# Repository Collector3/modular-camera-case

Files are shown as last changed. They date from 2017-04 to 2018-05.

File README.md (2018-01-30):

# Modular Raspberry Pi Camera Cases

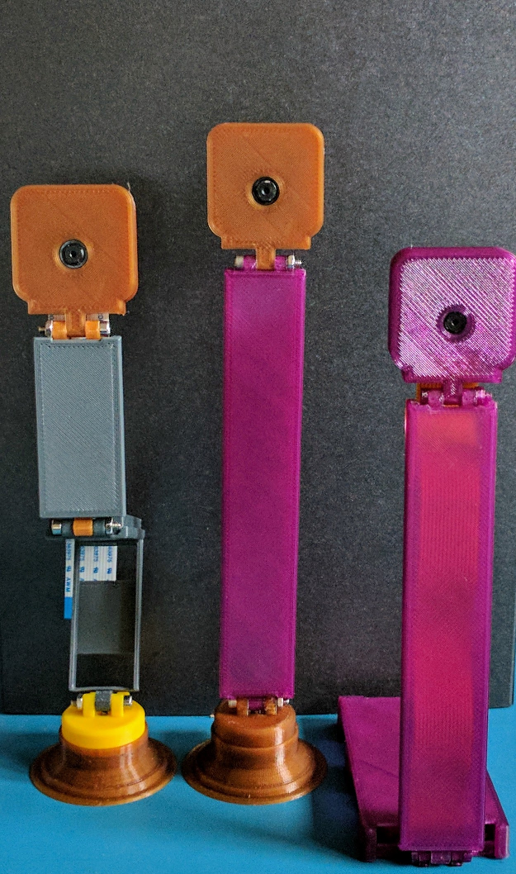
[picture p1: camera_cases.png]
Camera Case


Cases for the Raspberry Pi foundation's camera. v1/v2 are supported.

**Note**: This case needs M2.5 screws and nuts! The bill of materials with a source for getting these is listed below.

## Extrusion Width == 0.48mm

This case is also designed around an extrusion width of 0.48mm for strength (using a 0.4mm E3D nozzle) around small areas and parts. It makes a huge difference, so if the case isn't quite right, try adjusting the extrusion width.

## Assembly / Printing

Choose one of the cases below (they're plated together according to filename). They're also available separately for expansion (if a larger arm is desired, more/less sections, etc).

## Bill of Materials

This BOM lists the amount of screws for each setup. In reality, everything is usually sold in 25+ quantity packs, so just buy M2.5 screws and M2.5 hex nuts. There is extra spacing to use nylock nuts too if desired.

Of course, if you're set on doing so, threading a bit of filament through the
holes and gluing everything together can work just as well (if no future adjustments are desired). Zip ties also work, but don't look as good.

### Various configurations

#### Pi Zero Case + Long Arm

To split these for arranging on a bed in Slic3r, use the 'Split' option at the top [next to scale/cut]. These files include the **v2 camera enclosure by default**. The bottom-most stand is separate as well.

* File: [plated_pi_zero_case.stl](plated_pi_zero_case.stl) [purple, far right in the photos]
* 2x M2.5 x 16mm screw
* 2x M2.5 hex nut

#### Long Arm

* File: [plated_long_arm.stl](plated_long_arm.stl) [purple with brown/bronze top, center]
* 2x M2.5 x 16mm screw
* 2x M2.5 hex nut

#### Multi-jointed Arm

* File: [plated_multi_arm.stl](plated_multi_arm.stl) [yellow base, gray and brown/bronze top, left]
* 4x M2.5 x 16mm screw
* 4x M2.5 hex nut

#### Stand

* File: [Stand.stl](Stand.stl) [Brown/Bronze bottom in pictures]
* 1x: M2.5 x 16mm screw (pushed in through the top or bottom before joining
  with the smaller base [yellow in the picture])

#### RPi OEM Backpack

* File: rpi-zero-oem-case-backpack.stl [Red]
* 1x M2.5 20mm screw + 1x M2.5 Nylock

### Hardware source

(I don't have a good source for a metric hex key, but an appropriately sized one should be in many repair kits and multi-tools)

#### Trimcraft Aviation RC

* M2.5 Plain Hex Nut (25 pcs): https://www.trimcraftaviationrc.com/index.php?route=product/product&product_id=137
* M2.5 x 16mm Socket Cap Screw (25 pcs): https://www.trimcraftaviationrc.com/index.php?route=product/product&product_id=199

##### Materials Used (1.75mm PLA)

(These are the various types of PLA used in the photo above; basically a mix-and-match of whatever was loaded into the machine on the day that these were made)

* Purple: Ultimachine Purple Translucent PLA

* Yellow: Prusa PLA, OEM: [Plasty Mladec](http://www.plastymladec.cz/) 

* Brown: Proto-pasta High Performance HTPLA - Aromatic Coffee

* Gray: Atomic Filament Extreme Impact Gun Metal Gray v2 (a flex test of the impact modifier is present on the far left casing)

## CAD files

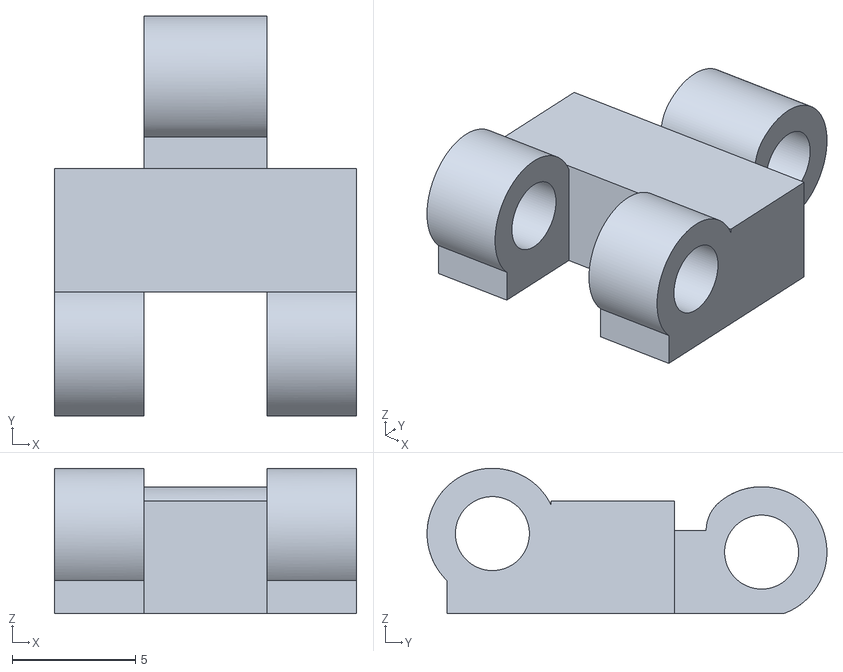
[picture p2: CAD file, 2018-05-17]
Spacer.stl
12.2 x 16.2 x 5.90

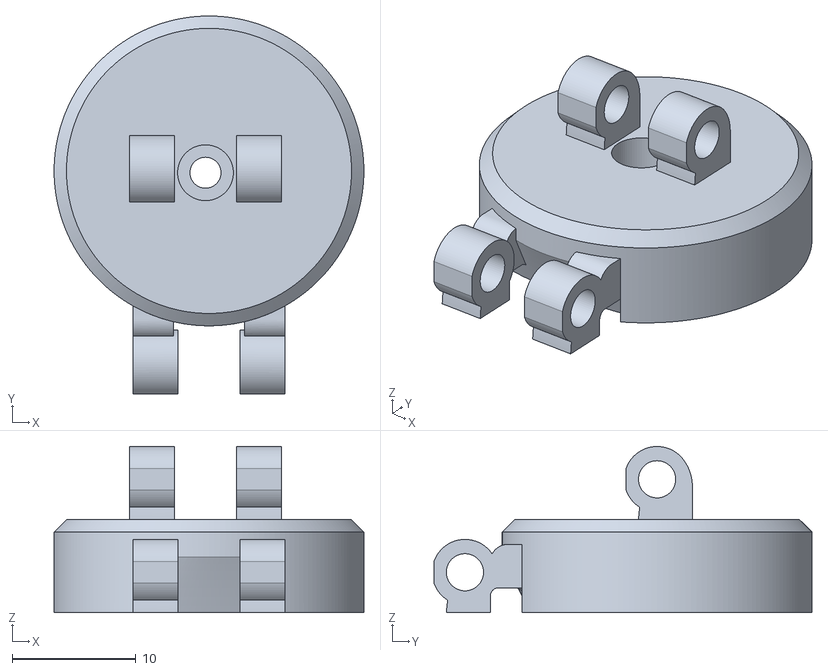
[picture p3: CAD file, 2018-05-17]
Base.stl
25.0 x 30.5 x 13.4

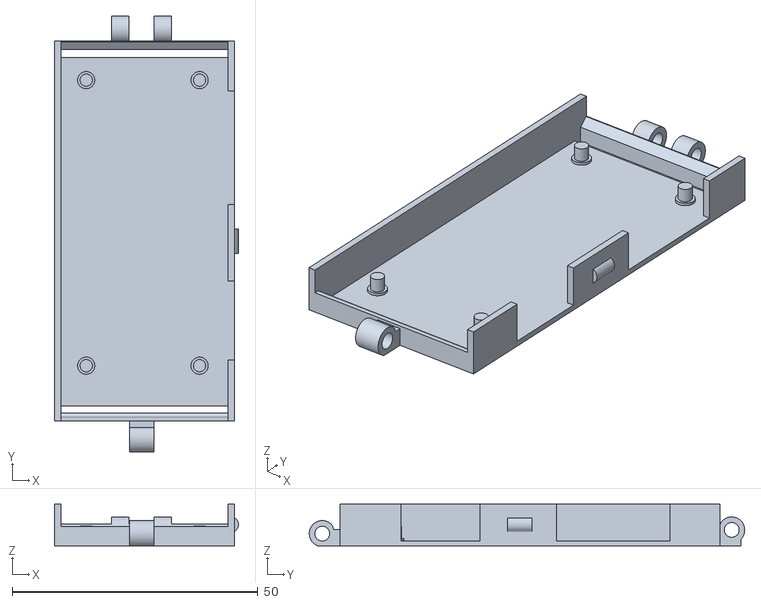
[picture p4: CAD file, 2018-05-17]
Pi Zero Cover - No GPIO.stl
37.4 x 88.5 x 8.50

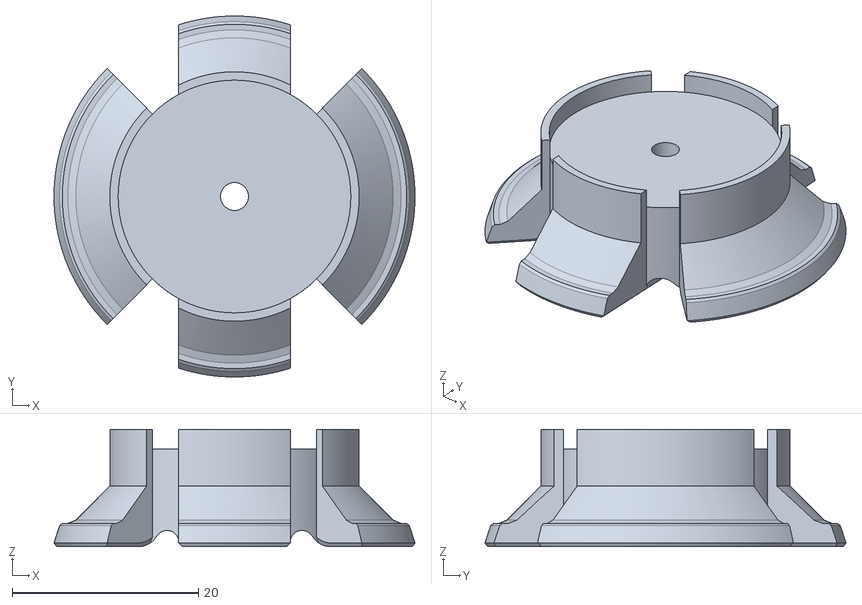
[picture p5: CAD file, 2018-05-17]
Stand.stl
38.8 x 38.8 x 12.6

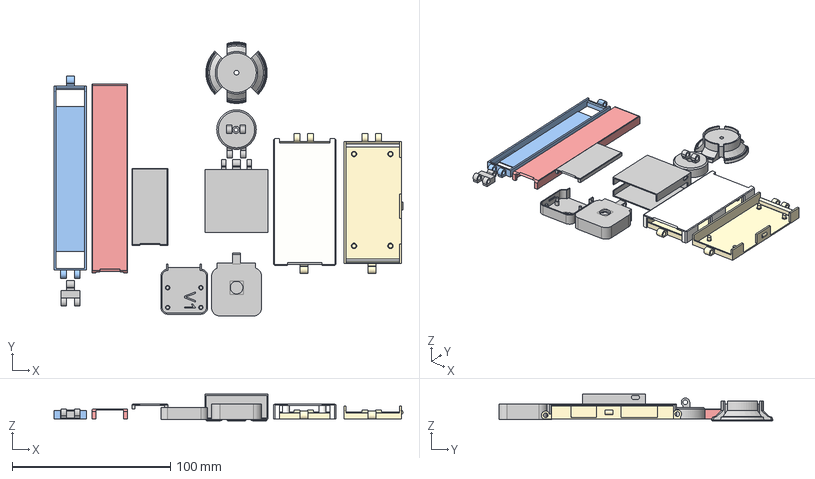
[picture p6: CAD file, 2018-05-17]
RPi_Camera_Pivotable_Source.stp
220.6 x 173.2 x 16.8 mm
Camera Holder
RPiCam-v2 v2

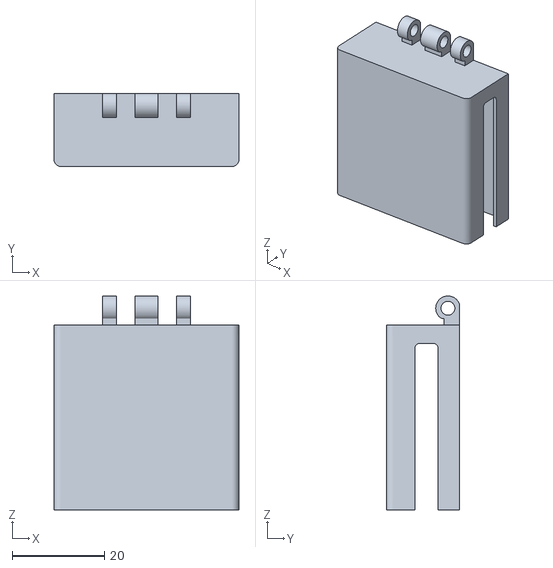
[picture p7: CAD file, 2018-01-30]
rpi-zero-oem-case-backpack.stl
40.0 x 15.8 x 46.3

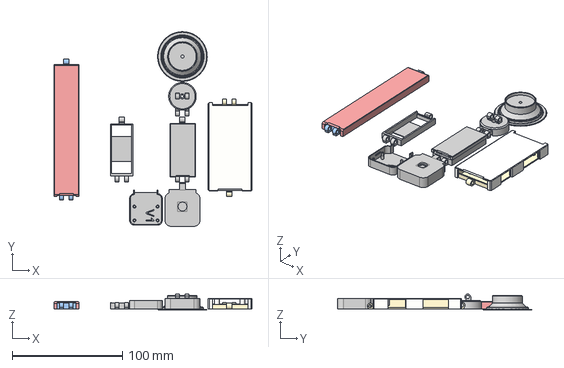
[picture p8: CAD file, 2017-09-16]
modular-camera-source.stp
179.3 x 176.3 x 14.4 mm
Camera Holder
RPiCam-v2 v2

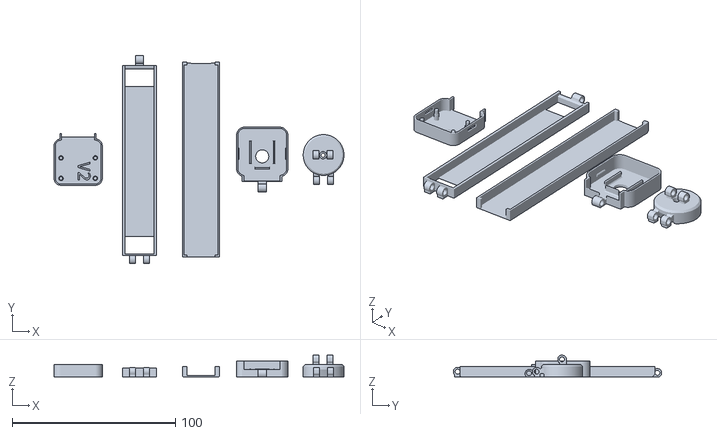
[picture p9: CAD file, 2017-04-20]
plated_long_arm.stl
177.7 x 127.7 x 13.4

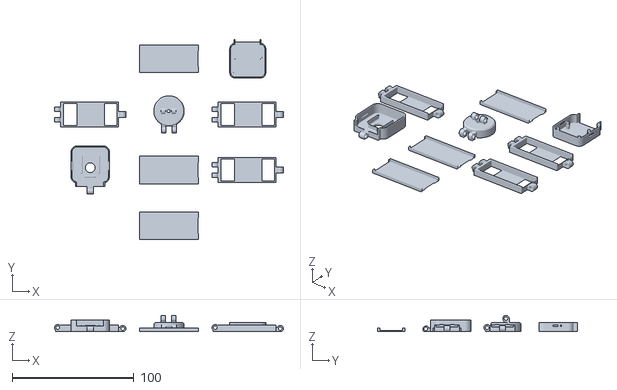
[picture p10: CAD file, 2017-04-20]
plated_multi_arm.stl
188.1 x 164.4 x 13.4

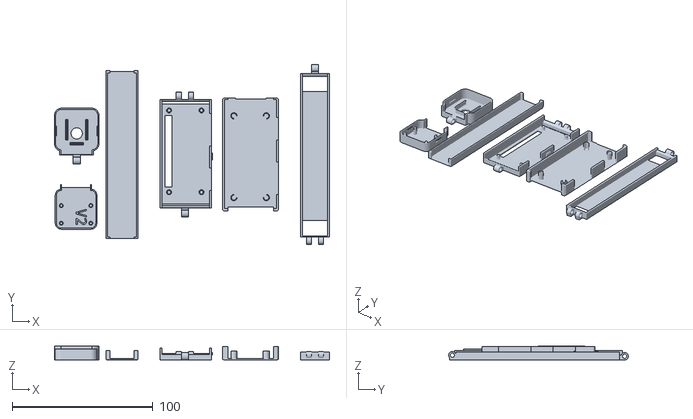
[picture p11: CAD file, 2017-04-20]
plated_pi_zero_case.stl
195.4 x 127.7 x 9.64

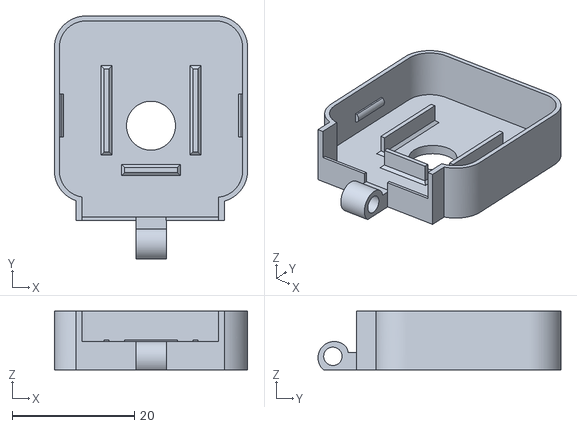
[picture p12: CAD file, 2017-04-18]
Camera Cover.stl
31.6 x 39.7 x 9.64

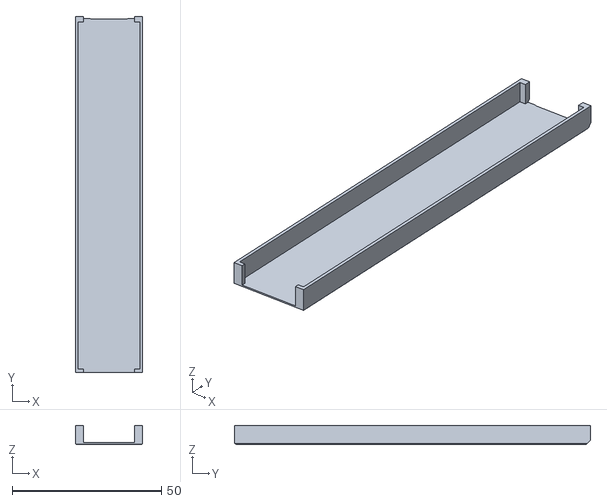
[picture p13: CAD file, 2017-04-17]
Long Center Cover.stl
22.6 x 119.4 x 6.50

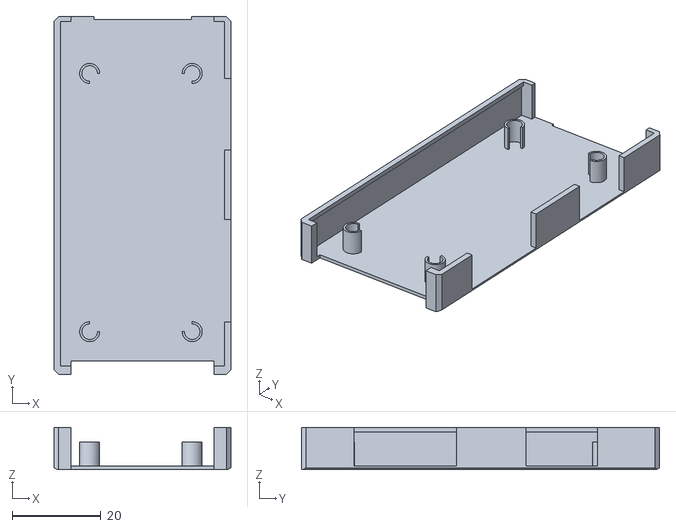
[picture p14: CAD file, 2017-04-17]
Pi Zero Cover.stl
39.7 x 80.5 x 9.50

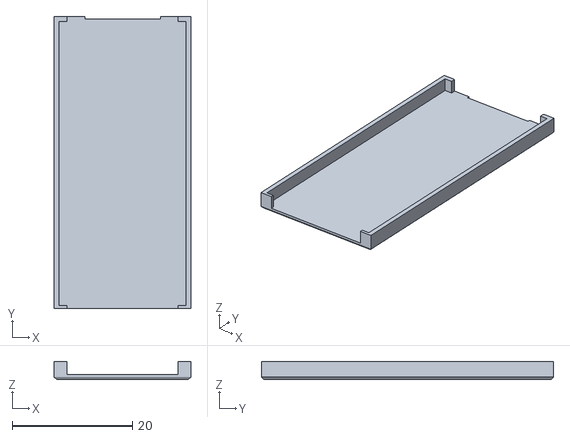
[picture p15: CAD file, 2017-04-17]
Center Cover.stl
22.8 x 48.6 x 3.00

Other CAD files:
Camera Case for v2 Camera.stl
Long Center Case.stl
Pi Zero Holder.stl
Center Case.stl
Camera Case for v1 Camera.stl

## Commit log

2017-04-17 Orient for FFF/FDM printing
    [Base.stl, Camera Case for v2 Camera.stl, Camera Cover.stl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]
2017-04-18 Latest changes (camera hole enlarged, pushed forward)
    [Base.stl, Camera Case for v1 Camera.stl, Camera Cover.stl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]
2017-04-18 Add everything plated files
    [everything.amf, everything.stl]
2017-04-20 Add notes about extrusion width and materials used in prototyping
2017-04-20 Add plated cases
    [plated_long_arm.stl, plated_multi_arm.stl, plated_pi_zero_case.stl]
2017-04-20 README update + pi zero case rename
    [Pi Zero Cover.stl, Pi Zero Holder.stl]
2017-04-25 Update filament vendor
2017-09-16 Add STEP file for external modding
    [modular-camera-source.stp]
2018-01-29 Add a case usable as a backpack for the Official RPi Zero Case
    [rpi-zero-oem-case-backpack.stl]
2018-01-30 Flip the backpack for easier printability
    [rpi-zero-oem-case-backpack.stl]
2018-05-17 Update modular-camera-case to match external sites
    [Base.stl, Pi Zero Cover - No GPIO.stl, RPi_Camera_Pivotable_Source.stp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]
